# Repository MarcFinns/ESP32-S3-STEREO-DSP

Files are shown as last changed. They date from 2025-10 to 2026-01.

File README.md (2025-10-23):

# ESP32-S3 STEREO DSP BOARD

A board with ESP32-S3, ADC, DAC, LCD display for audio application and beyond. 
While these components can be connected in principle on any breakout board for prototyping, proper power decoupling and series terminator resistors are necessary to limit noise and interference.
This board ensures that all signals are appropriately decoupled and routed, on a single layer PCB.

The board was used to develop the [PiratESP32 FM RDS STEREO ENCODER](https://github.com/MarcFinns/PiratESP32-FM-RDS-STEREO-ENCODER)

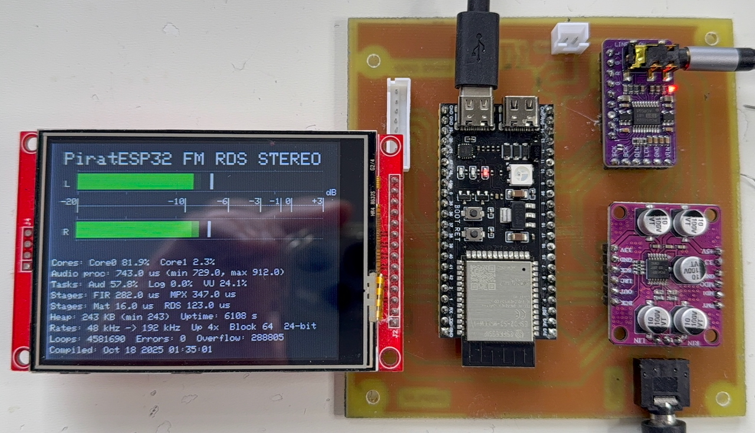
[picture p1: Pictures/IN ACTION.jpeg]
In action


## Features

### ESP32 Board
- **ESP32-S3 N16R8** with dual-core processor with SIMD (vector) instructions to boost DSP applications
- **ADC**: PCM1808 I2S audio ADC (24 bit, up to 96 kHz sample rate, I2S slave)
- **DAC**: PCM5102A I2S audio DAC (16/24/32 bit, up to 192 kHz sample rate, I2S slave)
- **Display (optional)** ILI9341 320×240 TFT LCD (SPI interface)
- **GPIO connector** for LED/buttons or anything else

## Pin Configuration

### I2S Audio
```
Master Clock (shared):  GPIO 8  (tested at 24.576 MHz MCLK)

ADC Input:
  BCK  (Bit Clock):     GPIO 4
  LRCK (Word Select):   GPIO 6
  DIN  (Serial Data):   GPIO 5

DAC Output:
  BCK  (Bit Clock):     GPIO 9
  LRCK (Word Select):   GPIO 11
  DOUT (Serial Data):   GPIO 10

ILI9341 TFT Display
	SCK  (SPI Clock):       GPIO 40
	MOS	I (SPI Data):        GPIO 41
	DC   (Data/Command):    GPIO 42
	CS   (Chip Select):     GPIO 1
	RST  (Reset):           GPIO 2

GPIO Connector
	3V3
	GPIO39
	GPIO38
	GPIO48
	GPIO47
	GPIO21
```

## Important notes

- Some PCM1808 ADC breakout boards have a **very aggressive low pass filter** (the filter is optional from the datasheet, and they chose a wrong capacitor value). This results in a lowpass filter at 6Khz! If sound is muffled, you can just desolder the caps (or break them, it is fine). See picture

- The board is designed to be powered 
both from USB on the ESP and from the Vin, 
without conflicts. However, to enable the board 
to work when powered via USB, it is often 
necessary to connect a jumper on the ESP32-
S3 board that enables 5V out. 
The location of the jumper depends on 
the flavour of the development board! **Look it up!**

- The board can be powered with a power supply connected to the Vin connector (12v max) so that it can work standalone / when not connected to a PC via USB. To that end, a LDO is included in the schematic. It can be skipped if only USB power is necessary. The LDO (AMS1117 family) can be either ADJ or 5V fixed version. A solder jumper on the PCB is provided to select the version. If fixed, connect SJ1 jumper to GND. If adj, connect to R divider. **If left not connected, bad things will happen**

- The PCB and schematic in the folder are correct. The pictures are of my first prototybe that had some mistakes, corrected later!

- SMD components are 0805 size. If uneasy with SMD, one could just redesign the PCB with through hole, keeping the schematic and even the routing - just make it larger

## Breakout boards

The following breakout boards are matching the PCB.
If different ones are used, schematic is still valid but re-routing of the PCB might become necessary.

- [ILI9341 Display](https://nl.aliexpress.com/item/32913890225.html)
- [PCM1808 ADC breakout board](https://nl.aliexpress.com/item/1005006749086540.html)
- [PCM5102A DAC breakout board](https://nl.aliexpress.com/item/1005009648364414.html)
- [ESP32-S3 N16R8](https://nl.aliexpress.com/item/1005007319706057.html)

## References

- [PCM1808 ADC datasheet](https://www.ti.com/lit/ds/symlink/pcm1808.pdf)
- [PCM5102A DAC datasheet](https://www.ti.com/lit/ds/symlink/pcm5102a.pdf)
- [ESP32-S3 documentation](https://www.espressif.com/sites/default/files/documentation/esp32-s3_technical_reference_manual_en.pdf)
- [ESP32 I2S Documentation](https://docs.espressif.com/projects/esp-idf/en/latest/esp32/api-reference/peripherals/i2s.html)

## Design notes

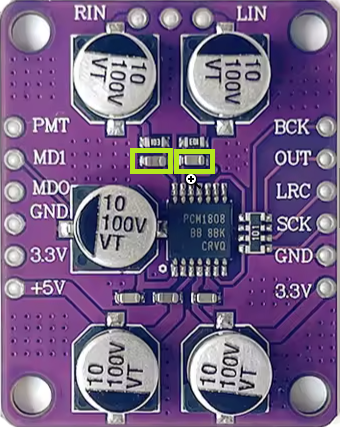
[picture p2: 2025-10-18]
Pictures/PCM1808 Audio ADC CAPS TO REMOVE.png

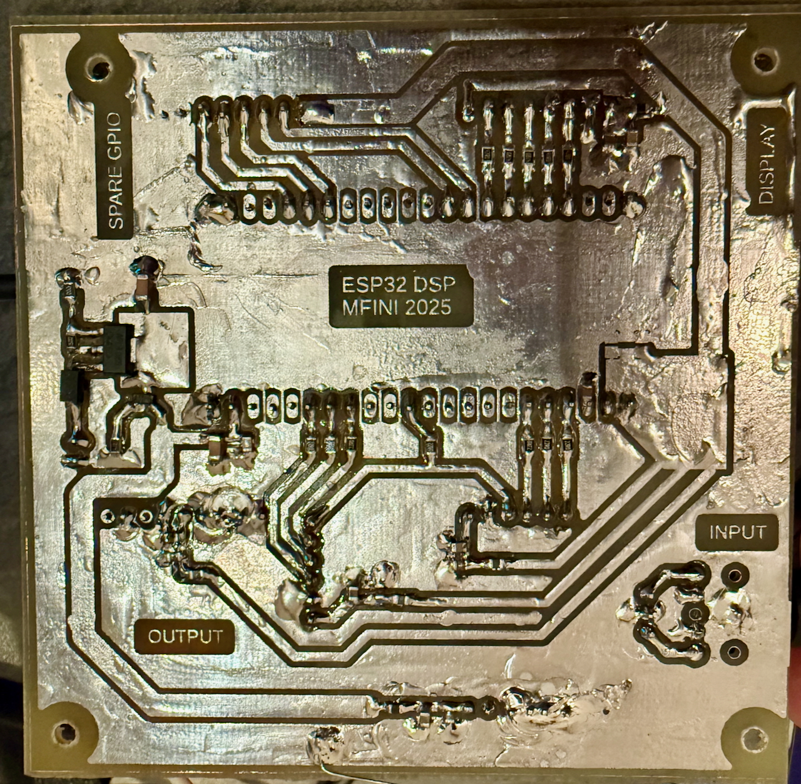
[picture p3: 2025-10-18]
Pictures/PCB BOTTOM.jpeg

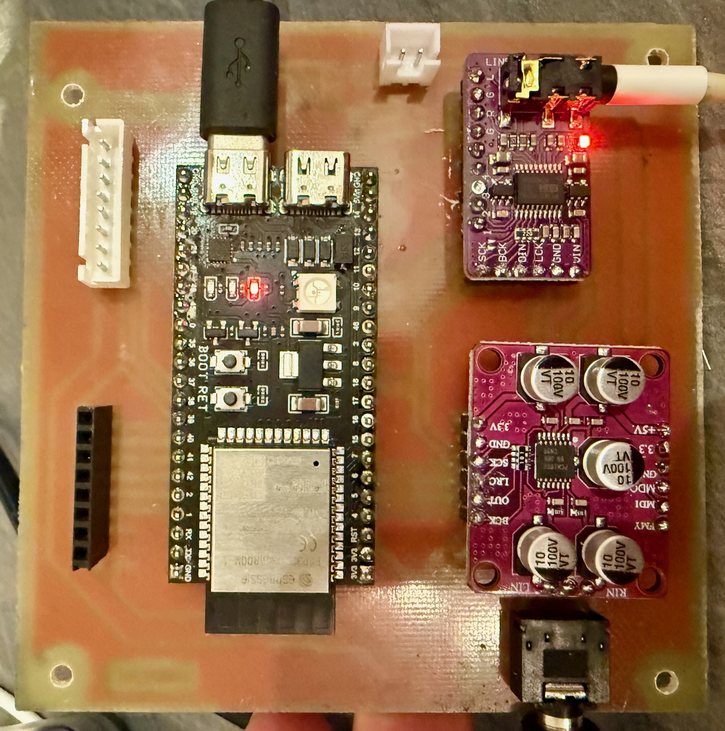
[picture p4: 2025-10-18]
Pictures/PCB TOP.jpeg

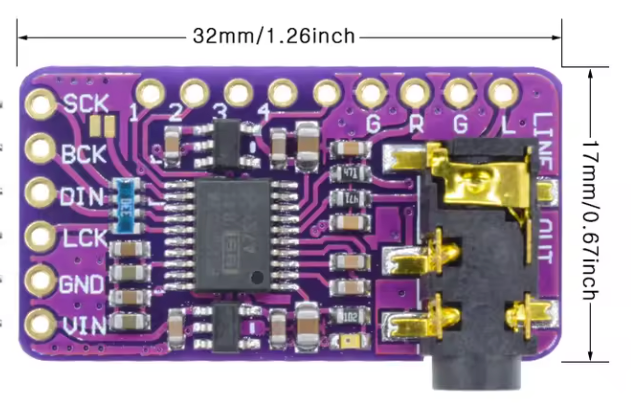
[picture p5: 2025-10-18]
Pictures/DSP5102a Audio DAC.png

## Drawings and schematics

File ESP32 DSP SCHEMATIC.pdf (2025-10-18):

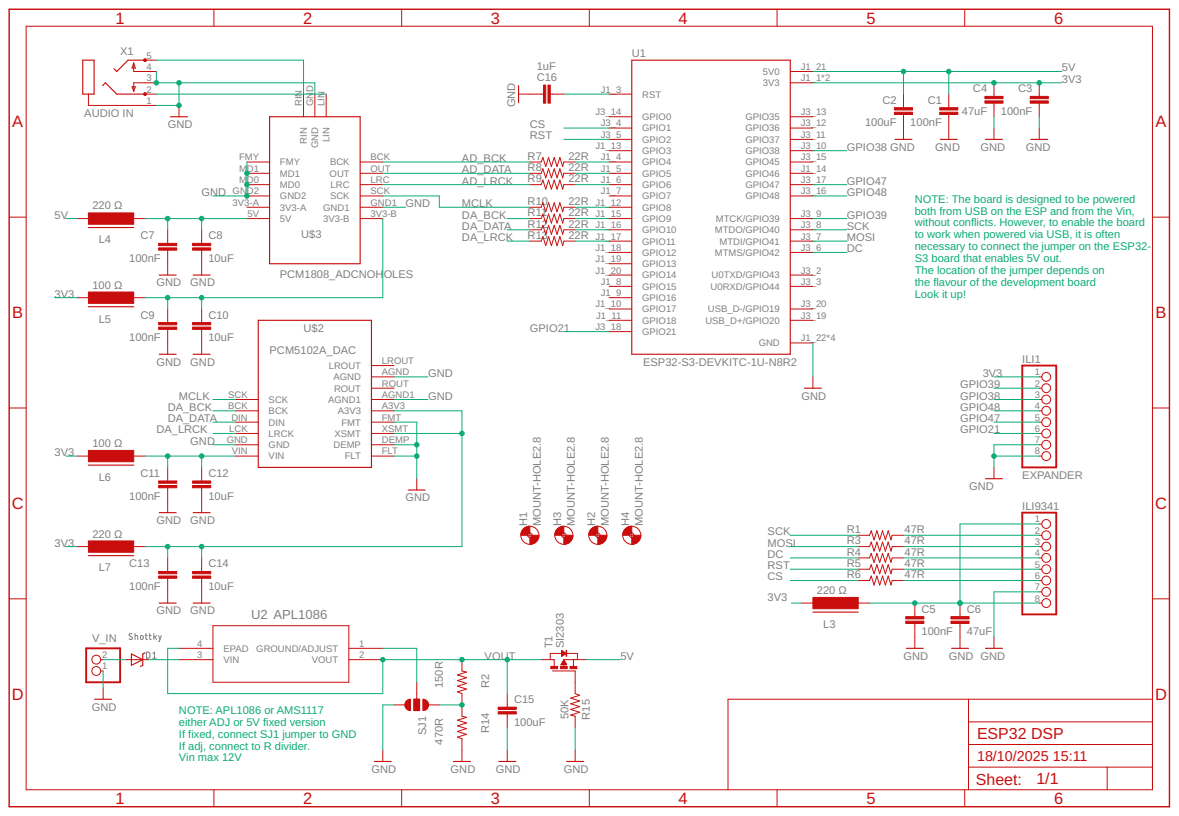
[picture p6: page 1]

NOTE: The board is designed to be powered
both from USB on the ESP and from the Vin, without conflicts. However, to enable the board
to work when powered via USB, it is often
necessary to connect the jumper on the ESP32- S3 board that enables 5V out. The location of the jumper depends on

the flavour of the development board
Look it up!

NOTE: APL1086 or AMS1117
either ADJ or 5V fixed version
If fixed, connect SJ1 jumper to GND
If adj, connect to R divider. Vin max 12V

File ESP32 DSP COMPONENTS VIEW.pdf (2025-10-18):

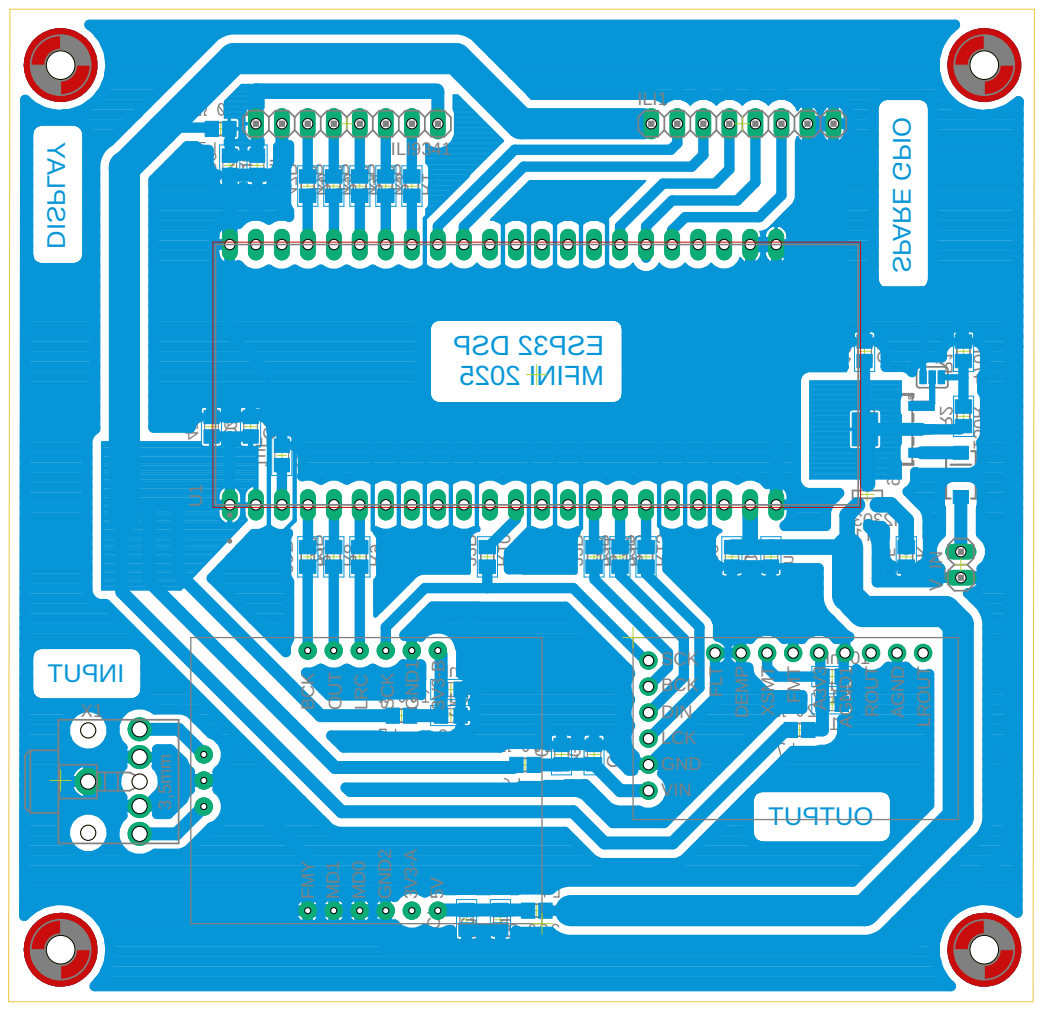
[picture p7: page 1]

ROUT AGND1 A3V3 FMT XSMT DEMP

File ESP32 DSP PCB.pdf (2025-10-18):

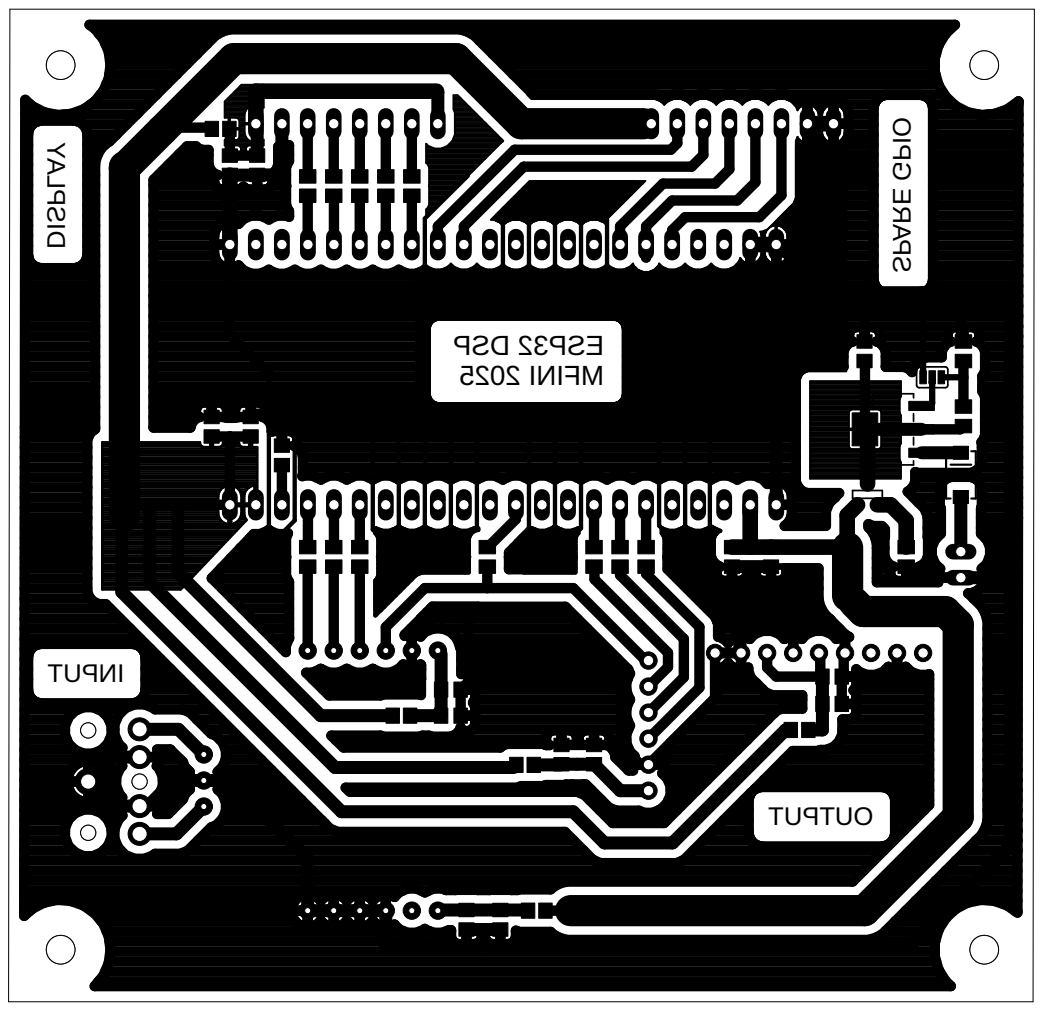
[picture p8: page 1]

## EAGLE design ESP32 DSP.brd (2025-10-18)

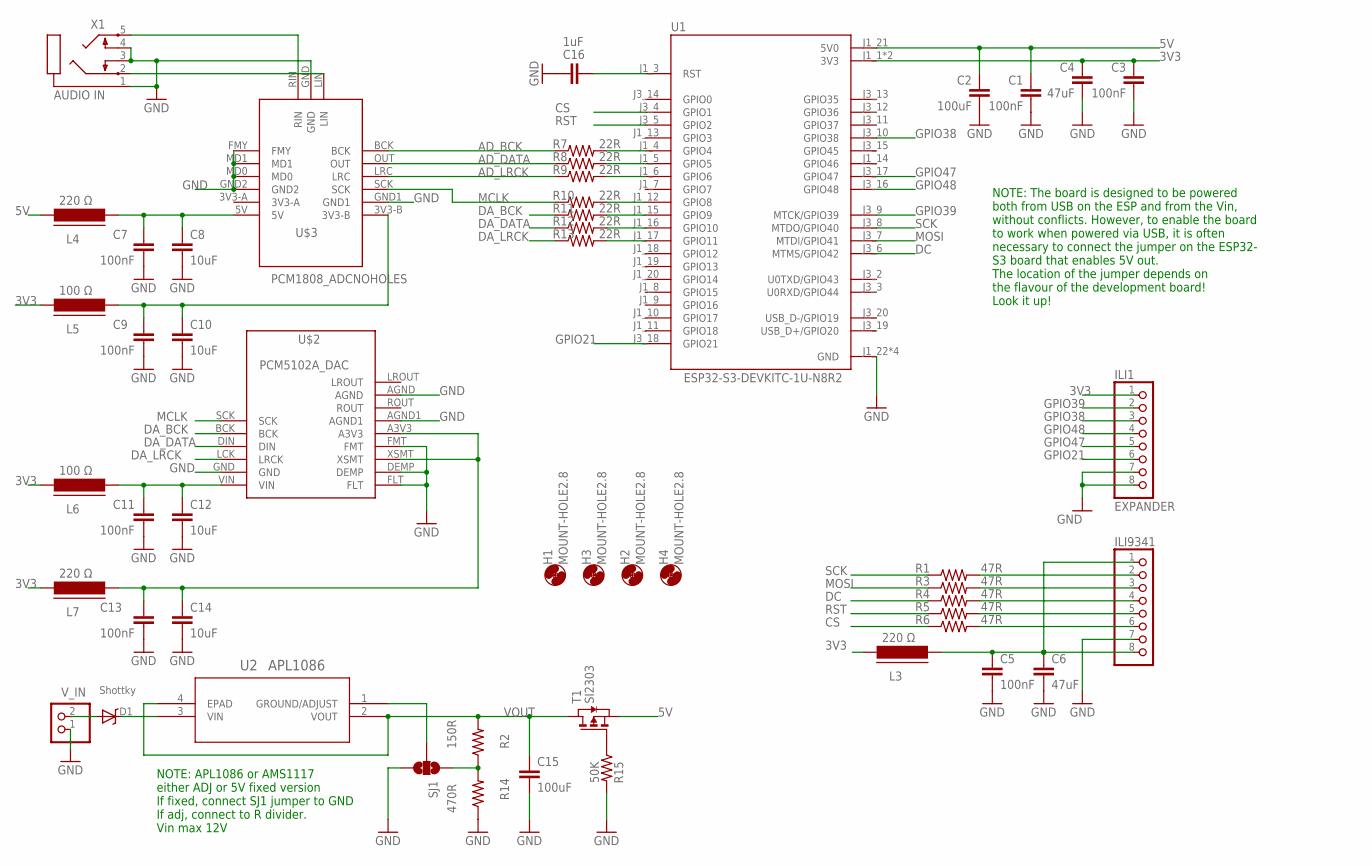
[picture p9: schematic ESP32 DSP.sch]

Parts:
C1, C3, C5, C7, C9, C11, C13: 100nF; C0805
C2, C15: 100uF; C0805
C4, C6: 47uF; C0805
C8, C10, C12, C14: 10uF; C0805
C16: 1uF; C0805
D1: Shottky; SMA-403D
H1, H2, H3, H4: MOUNT-HOLE2.8; 2,8
ILI1: EXPANDER; 1X08
ILI9341: PINHD-1X8; 1X08
L3, L4, L7: 220 Ω; FB805
L5, L6: 100 Ω; FB805
R1, R3, R4, R5, R6: 47R; M0805
R2: 150R; M0805
R7, R8, R9, R10, R11, R12, R13: 22R; M0805
R14: 470R; M0805
R15: 50K; M0805
SJ1: SOLDERJUMPER_2WAYS; SJ_3
T1: SI2303; SOT-23
U1: ESP32-S3-DEVKITC-1U-N8R2; XCVR_ESP32-S3-DEVKITC-1U-N8R2
U2: APL1086; SOT_AMS_ADS
U$2: PCM5102A_DAC; I2S_PCM_5100_SOUNDCARD
U$3: PCM1808_ADCNOHOLES; CMJCU-1808-NOHOLES
V_IN: 5V; 1X02
X1: AUDIO IN; STX3100

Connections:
3V3: C3.1, C4.1, ILI1.1, L3.1, L5.1, L6.1, L7.1, U1.J1_1 (3V3), U1.J1_2 (3V3)
5V: C1.1, C2.1, L4.1, T1.2 (S), U1.J1_21 (5V0)
AD_BCK: R7.1, U$3.BCK
AD_DATA: R8.1, U$3.OUT
AD_LRCK: R9.1, U$3.LRC
CS: R6.1, U1.J3_4 (GPIO1)
DA_BCK: R11.1, U$2.BCK
DA_DATA: R12.1, U$2.DIN
DA_LRCK: R13.1, U$2.LCK (LRCK)
DC: R4.1, U1.J3_6 (MTMS/GPIO42)
GND: C1.2, C2.2, C3.2, C4.2, C5.2, C6.2, C7.2, C8.2, C9.2, C10.2, C11.2, C12.2, C13.2, C14.2, C15.2, C16.2, ILI1.7, ILI1.8, ILI9341.7, R14.1, R15.2, SJ1.3, U1.J1_22 (GND), U1.J3_1 (GND), U1.J3_21 (GND), U1.J3_22 (GND), U$2.AGND, U$2.AGND1, U$2.DEMP, U$2.FLT, U$2.FMT, U$2.GND, U$3.FMY, U$3.GND, U$3.GND1, U$3.GND2, U$3.MD0, U$3.MD1, V_IN.1, X1.1, X1.3, X1.4
GPIO21: ILI1.6, U1.J3_18 (GPIO21)
GPIO38: ILI1.3, U1.J3_10 (GPIO38)
GPIO39: ILI1.2, U1.J3_9 (MTCK/GPIO39)
GPIO47: ILI1.5, U1.J3_17 (GPIO47)
GPIO48: ILI1.4, U1.J3_16 (GPIO48)
MCLK: R10.1, U$2.SCK, U$3.SCK
MOSI: R3.1, U1.J3_7 (MTDI/GPIO41)
unnamed: ILI9341.2, R1.2
unnamed: ILI9341.3, R3.2
unnamed: ILI9341.4, R4.2
unnamed: ILI9341.5, R5.2
unnamed: ILI9341.6, R6.2
unnamed: C11.1, C12.1, L6.2, U$2.VIN
unnamed: C13.1, C14.1, L7.2, U$2.A3V3, U$2.XSMT
unnamed: U$3.RIN, X1.5
unnamed: U$3.LIN, X1.2
unnamed: R2.1, R14.2, SJ1.1
unnamed: D1.C, U2.3 (VIN)
unnamed: C16.1, U1.J1_3 (RST)
unnamed: SJ1.2, U2.1 (GROUND/ADJUST)
unnamed: R15.1, T1.3 (G)
unnamed: R7.2, U1.J1_4 (GPIO4)
unnamed: R8.2, U1.J1_5 (GPIO5)
unnamed: R9.2, U1.J1_6 (GPIO6)
unnamed: R10.2, U1.J1_12 (GPIO8)
unnamed: R11.2, U1.J1_15 (GPIO9)
unnamed: R12.2, U1.J1_16 (GPIO10)
unnamed: R13.2, U1.J1_17 (GPIO11)
unnamed: C9.1, C10.1, L5.2, U$3.3V3-B
unnamed: C7.1, C8.1, L4.2, U$3.5V
unnamed: C5.1, C6.1, ILI9341.1, ILI9341.8, L3.2
RST: R5.1, U1.J3_5 (GPIO2)
SCK: R1.1, U1.J3_8 (MTDO/GPIO40)
VOUT: C15.1, R2.2, T1.1 (D), U2.2 (VOUT), U2.4 (EPAD)
V_IN: D1.A, V_IN.2

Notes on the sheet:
NOTE: APL1086 or AMS1117 either ADJ or 5V fixed version If fixed, connect SJ1 jumper to GND If adj, connect to R divider. Vin max 12V
NOTE: The board is designed to be powered both from USB on the ESP and from the Vin, without conflicts. However, to enable the board to work when powered via USB, it is often necessary to connect the jumper on the ESP32- S3 board that enables 5V out. The location of the jumper depends on the flavou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

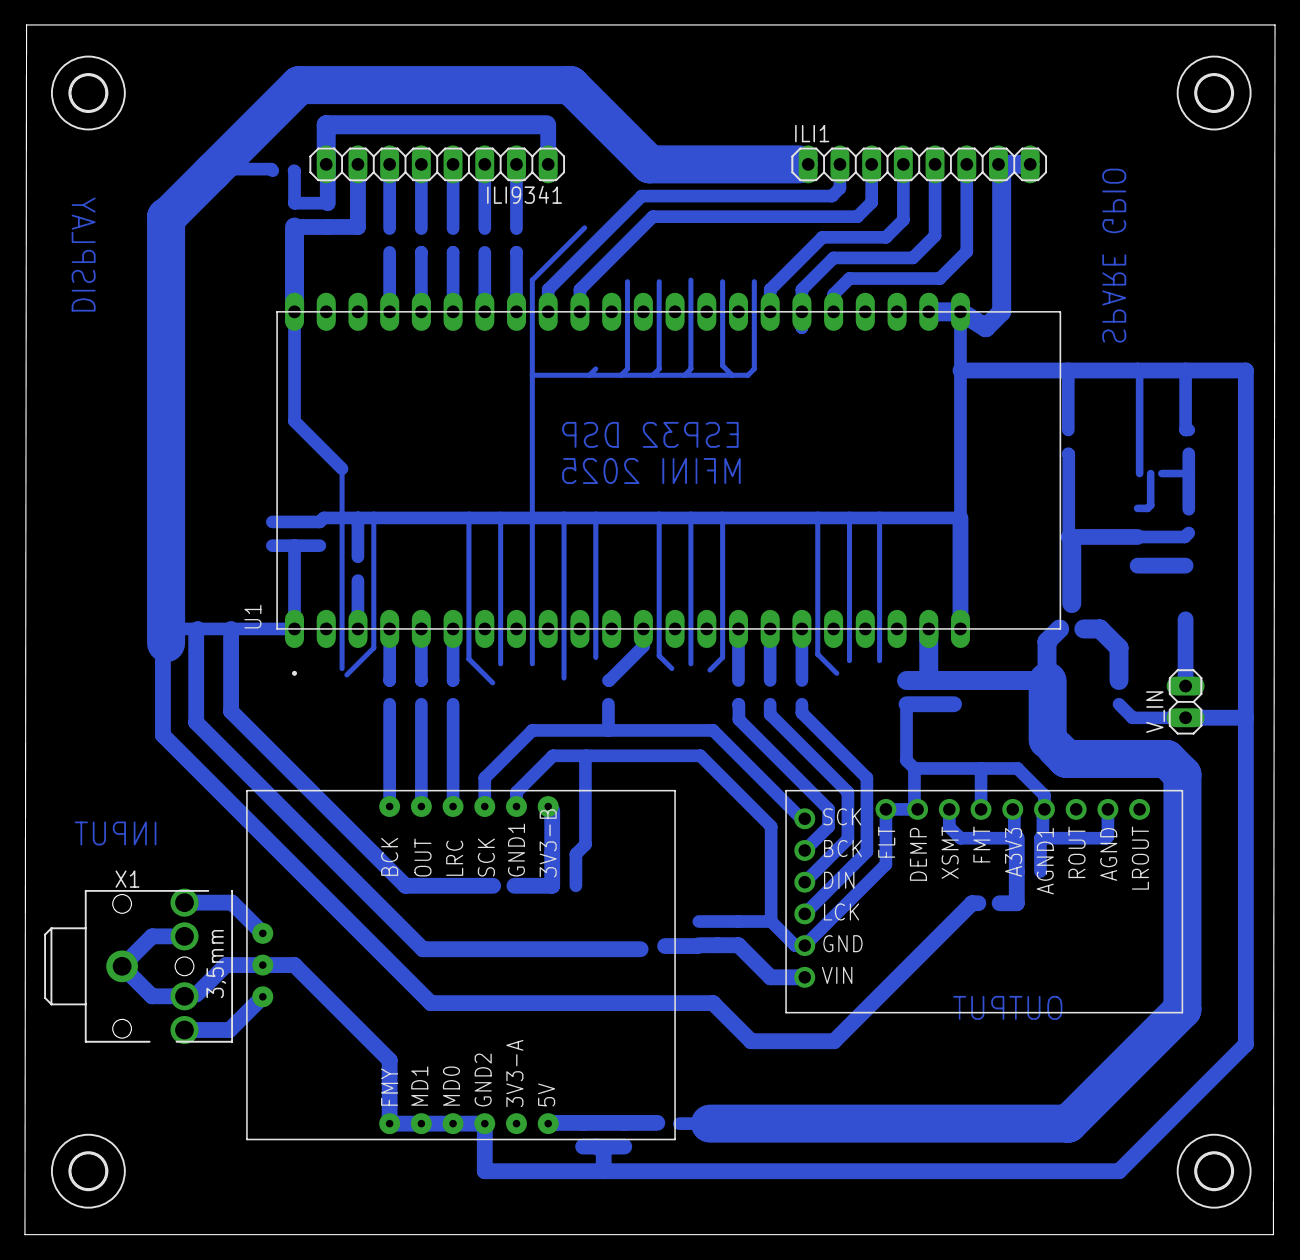
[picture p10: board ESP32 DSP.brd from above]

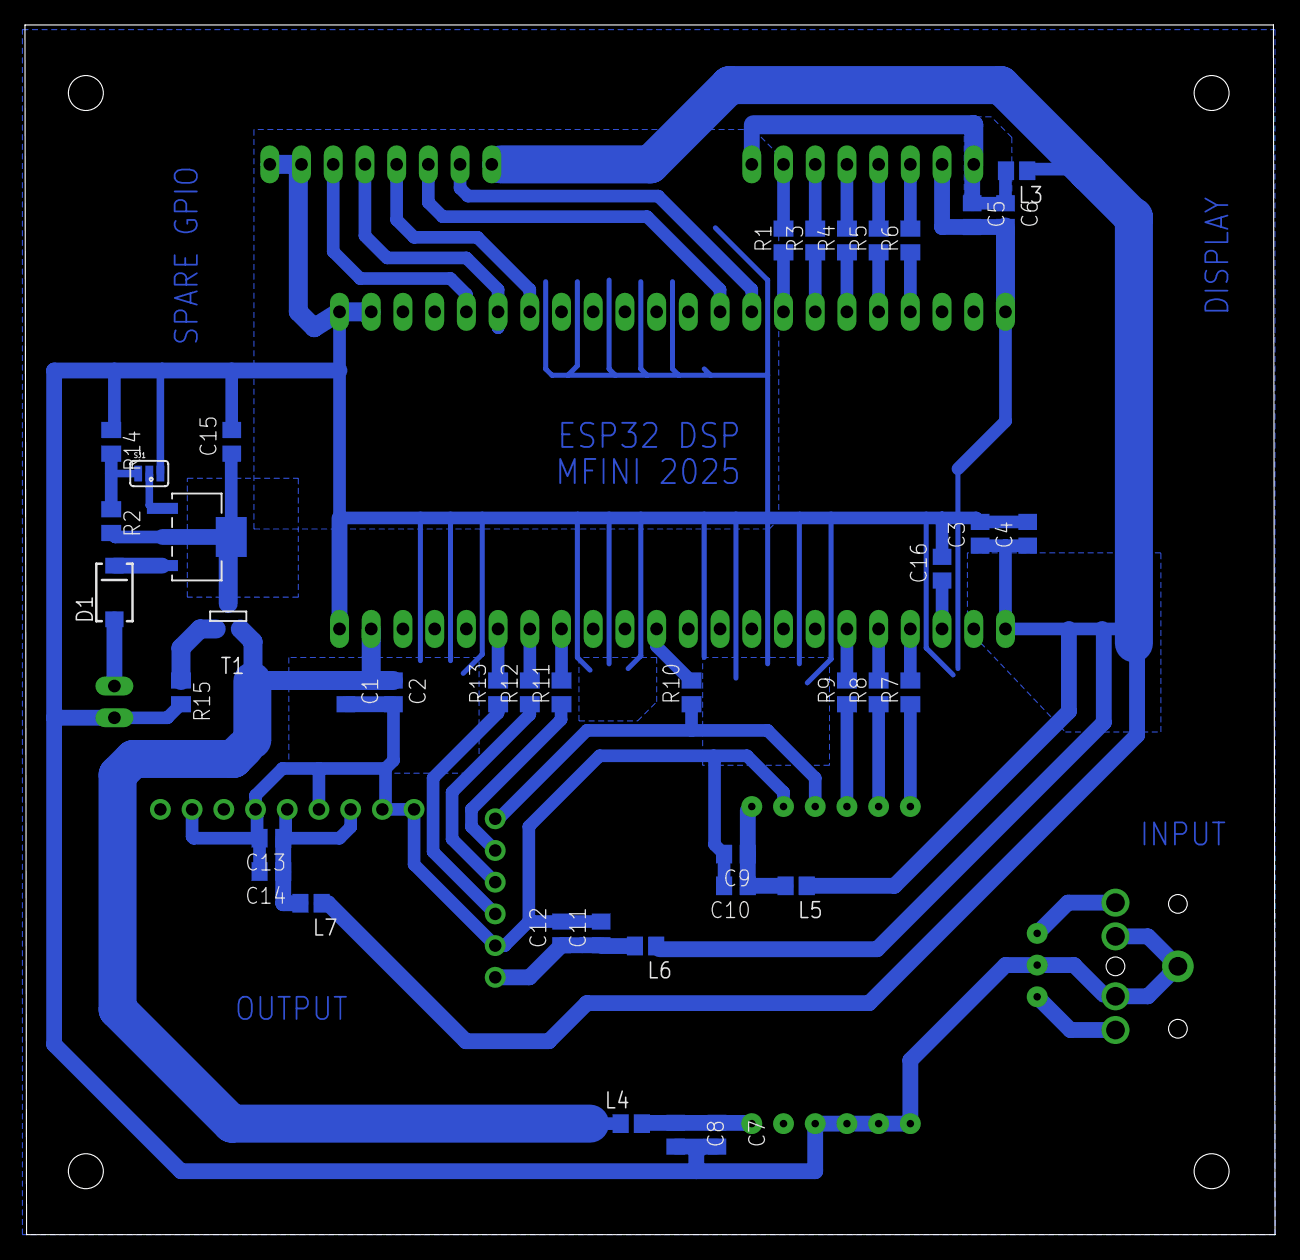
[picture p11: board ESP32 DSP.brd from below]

Board: 2 copper layers, 100.1 x 96.9 mm, 51 parts (40 on the bottom side), 46 nets.

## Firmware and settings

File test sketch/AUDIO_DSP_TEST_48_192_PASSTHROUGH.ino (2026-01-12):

/*
  ESP32-S3 Audio DSP: 48kHz ADC -> 4x Upsample -> 192kHz DAC

  Hardware:
  - PCM1808 ADC (slave mode) @ 48 kHz, 24-bit
  - PCM5102A DAC (slave mode) @ 192 kHz, 24-bit
  - Shared MCLK: 24.576 MHz on GPIO8

  Board: ESP32S3 Dev Module (Arduino-ESP32 3.x)
*/

#include <driver/gpio.h>
#include <driver/i2s_std.h>

// ==== Pin Configuration ====
#define PIN_MCLK 8 // Shared MCLK 24.576 MHz

// DAC (I2S1 - TX) - PCM5102A
#define PIN_DAC_BCK 9
#define PIN_DAC_LRCK 11
#define PIN_DAC_DOUT 10

// ADC (I2S0 - RX) - PCM1808
#define PIN_ADC_BCK 4
#define PIN_ADC_LRCK 6
#define PIN_ADC_DIN 5

// ==== Audio Configuration ====
#define SAMPLE_RATE_ADC 48000
#define SAMPLE_RATE_DAC 192000
#define UPSAMPLE_FACTOR 4
#define BLOCK_SIZE 64 // Frames per block (reduced for lower latency)
#define BITS_PER_SAMPLE 24
#define BYTES_PER_SAMPLE 4 // 24-bit in 32-bit container

// I2S channel handles
i2s_chan_handle_t tx_handle = NULL;
i2s_chan_handle_t rx_handle = NULL;

// Audio buffers
int32_t rx_buffer[BLOCK_SIZE * 2];                   // Stereo input @ 48kHz
int32_t tx_buffer[BLOCK_SIZE * UPSAMPLE_FACTOR * 2]; // Stereo output @ 192kHz

// ==== Improved Upsampler: Cubic Hermite Interpolation ====
// Much better than linear, avoids aliasing artifacts, simple & fast

// Cubic Hermite basis functions for smooth interpolation
static inline float hermite_h00(float t) { return 2*t*t*t - 3*t*t + 1; }
static inline float hermite_h10(float t) { return t*t*t - 2*t*t + t; }
static inline float hermite_h01(float t) { return -2*t*t*t + 3*t*t; }
static inline float hermite_h11(float t) { return t*t*t - t*t; }

// History buffer for samples before current block
static int32_t prev_L = 0, prev_R = 0;

void upsample_4x_polyphase(const int32_t *input, int32_t *output,
                           size_t num_frames)
{
  // 4x cubic Hermite interpolation
  // Uses smooth interpolation curves instead of linear, much better quality
  for (size_t i = 0; i < num_frames; i++)
  {
    // Get surrounding samples (with history)
    int32_t L0 = (i == 0) ? prev_L : input[(i - 1) * 2];
    int32_t R0 = (i == 0) ? prev_R : input[(i - 1) * 2 + 1];
    int32_t L1 = input[i * 2];
    int32_t R1 = input[i * 2 + 1];
    int32_t L2 = (i == num_frames - 1) ? L1 : input[(i + 1) * 2];
    int32_t R2 = (i == num_frames - 1) ? R1 : input[(i + 1) * 2 + 1];
    int32_t L3 = (i >= num_frames - 2) ? L2 : input[(i + 2) * 2];
    int32_t R3 = (i >= num_frames - 2) ? R2 : input[(i + 2) * 2 + 1];

    // Compute derivatives for Hermite spline (simple 3-point approximation)
    float m1_L = (float)(L2 - L0) * 0.5f;
    float m2_L = (float)(L3 - L1) * 0.5f;
    float m1_R = (float)(R2 - R0) * 0.5f;
    float m2_R = (float)(R3 - R1) * 0.5f;

    // Generate 4 output samples per input sample
    for (int frac = 0; frac < 4; frac++)
    {
      float t = frac * 0.25f;  // Fractional position 0, 0.25, 0.5, 0.75

      // Hermite basis evaluation
      float h00 = hermite_h00(t);
      float h10 = hermite_h10(t);
      float h01 = hermite_h01(t);
      float h11 = hermite_h11(t);

      // Interpolate left and right channels
      float out_L_norm = h00 * (float)L1 / 2147483648.0f +
                         h10 * m1_L / 2147483648.0f +
                         h01 * (float)L2 / 2147483648.0f +
                         h11 * m2_L / 2147483648.0f;

      float out_R_norm = h00 * (float)R1 / 2147483648.0f +
                         h10 * m1_R / 2147483648.0f +
                         h01 * (float)R2 / 2147483648.0f +
                         h11 * m2_R / 2147483648.0f;

      // Convert back to MSB-aligned 32-bit
      int32_t out_L = (int32_t)(out_L_norm * 2147483648.0f);
      int32_t out_R = (int32_t)(out_R_norm * 2147483648.0f);

      // Clamp to prevent overflow
      if (out_L > 2147483647) out_L = 2147483647;
      if (out_L < -2147483648) out_L = -2147483648;
      if (out_R > 2147483647) out_R = 2147483647;
      if (out_R < -2147483648) out_R = -2147483648;

      size_t out_idx = i * 8 + frac * 2;
      output[out_idx] = out_L;
      output[out_idx + 1] = out_R;
    }
  }

  // Save last sample for next block
  if (num_frames > 0)
  {
    prev_L = input[(num_frames - 1) * 2];
    prev_R = input[(num_frames - 1) * 2 + 1];
  }
}

// ==== I2S Setup Functions ====

bool setup_i2s_tx()
{
  Serial.println("Initializing I2S TX (DAC @ 192kHz)...");

  // Channel configuration
  i2s_chan_config_t chan_cfg =
      I2S_CHANNEL_DEFAULT_CONFIG(I2S_NUM_1, I2S_ROLE_MASTER);
  chan_cfg.auto_clear = true;
  chan_cfg.dma_desc_num = 6;
  chan_cfg.dma_frame_num = 240;

  esp_err_t ret = i2s_new_channel(&chan_cfg, &tx_handle, NULL);
  if (ret != ESP_OK)
  {
    Serial.printf("Failed to create TX channel: %d\n", ret);
    return false;
  }

  // Slot configuration for PCM5102A
  i2s_std_slot_config_t slot_cfg = I2S_STD_PHILIPS_SLOT_DEFAULT_CONFIG(
      I2S_DATA_BIT_WIDTH_32BIT, I2S_SLOT_MODE_STEREO);
  slot_cfg.slot_bit_width = I2S_SLOT_BIT_WIDTH_32BIT;
  slot_cfg.ws_width = 32;
  slot_cfg.ws_pol = false;
  slot_cfg.bit_shift = true;
  slot_cfg.left_align = true; // PCM5102A expects MSB-aligned data
  slot_cfg.big_endian = false;
  slot_cfg.bit_order_lsb = false;

  // Clock configuration
  i2s_std_clk_config_t clk_cfg = {};
  clk_cfg.sample_rate_hz = SAMPLE_RATE_DAC;
  clk_cfg.clk_src = I2S_CLK_SRC_PLL_160M;
  clk_cfg.mclk_multiple = I2S_MCLK_MULTIPLE_128;

  // GPIO configuration
  i2s_std_gpio_config_t gpio_cfg = {};
  gpio_cfg.mclk = (gpio_num_t)PIN_MCLK;
  gpio_cfg.bclk = (gpio_num_t)PIN_DAC_BCK;
  gpio_cfg.ws = (gpio_num_t)PIN_DAC_LRCK;
  gpio_cfg.dout = (gpio_num_t)PIN_DAC_DOUT;
  gpio_cfg.din = I2S_GPIO_UNUSED;
  gpio_cfg.invert_flags.mclk_inv = false;
  gpio_cfg.invert_flags.bclk_inv = false;
  gpio_cfg.invert_flags.ws_inv = false;

  // Standard mode configuration
  i2s_std_config_t std_cfg = {};
  std_cfg.clk_cfg = clk_cfg;
  std_cfg.slot_cfg = slot_cfg;
  std_cfg.gpio_cfg = gpio_cfg;

  ret = i2s_channel_init_std_mode(tx_handle, &std_cfg);
  if (ret != ESP_OK)
  {
    Serial.printf("Failed to init TX std mode: %d\n", ret);
    return false;
  }

  ret = i2s_channel_enable(tx_handle);
  if (ret != ESP_OK)
  {
    Serial.printf("Failed to enable TX channel: %d\n", ret);
    return false;
  }

  Serial.println("I2S TX initialized successfully");
  Serial.printf("  Sample Rate: %d Hz\n", SAMPLE_RATE_DAC);
  Serial.printf("  MCLK: %.3f MHz (GPIO%d)\n",
                (SAMPLE_RATE_DAC * 128) / 1000000.0, PIN_MCLK);
  Serial.printf("  BCK: %.3f MHz (GPIO%d)\n",
                (SAMPLE_RATE_DAC * 64) / 1000000.0, PIN_DAC_BCK);
  Serial.printf("  LRCK: %d Hz (GPIO%d)\n", SAMPLE_RATE_DAC, PIN_DAC_LRCK);

  return true;
}

bool setup_i2s_rx()
{
  Serial.println("Initializing I2S RX (ADC @ 48kHz)...");

  // Channel configuration
  i2s_chan_config_t chan_cfg =
      I2S_CHANNEL_DEFAULT_CONFIG(I2S_NUM_0, I2S_ROLE_MASTER);
  chan_cfg.auto_clear = true;
  chan_cfg.dma_desc_num = 6;
  chan_cfg.dma_frame_num = 240;

  esp_err_t ret = i2s_new_channel(&chan_cfg, NULL, &rx_handle);
  if (ret != ESP_OK)
  {
    Serial.printf("Failed to create RX channel: %d\n", ret);
    return false;
  }

  // Slot configuration for PCM1808
  i2s_std_slot_config_t slot_cfg = I2S_STD_PHILIPS_SLOT_DEFAULT_CONFIG(
      I2S_DATA_BIT_WIDTH_32BIT, I2S_SLOT_MODE_STEREO);
  slot_cfg.slot_bit_width = I2S_SLOT_BIT_WIDTH_32BIT;
  slot_cfg.ws_width = 32;
  slot_cfg.ws_pol = false;
  slot_cfg.bit_shift = true;
  slot_cfg.left_align = true; // PCM1808 outputs MSB-aligned data
  slot_cfg.big_endian = false;
  slot_cfg.bit_order_lsb = false;

  // Clock configuration
  i2s_std_clk_config_t clk_cfg = {};
  clk_cfg.sample_rate_hz = SAMPLE_RATE_ADC;
  clk_cfg.clk_src = I2S_CLK_SRC_PLL_160M;
  clk_cfg.mclk_multiple = I2S_MCLK_MULTIPLE_512;

  // GPIO configuration
  i2s_std_gpio_config_t gpio_cfg = {};
  gpio_cfg.mclk = I2S_GPIO_UNUSED; // TX already drives MCLK
  gpio_cfg.bclk = (gpio_num_t)PIN_ADC_BCK;
  gpio_cfg.ws = (gpio_num_t)PIN_ADC_LRCK;
  gpio_cfg.dout = I2S_GPIO_UNUSED;
  gpio_cfg.din = (gpio_num_t)PIN_ADC_DIN;
  gpio_cfg.invert_flags.mclk_inv = false;
  gpio_cfg.invert_flags.bclk_inv = false;
  gpio_cfg.invert_flags.ws_inv = false;

  // Standard mode configuration
  i2s_std_config_t std_cfg = {};
  std_cfg.clk_cfg = clk_cfg;
  std_cfg.slot_cfg = slot_cfg;
  std_cfg.gpio_cfg = gpio_cfg;

  ret = i2s_channel_init_std_mode(rx_handle, &std_cfg);
  if (ret != ESP_OK)
  {
    Serial.printf("Failed to init RX std mode: %d\n", ret);
    return false;
  }

  ret = i2s_channel_enable(rx_handle);
  if (ret != ESP_OK)
  {
    Serial.printf("Failed to enable RX channel: %d\n", ret);
    return false;
  }

  Serial.println("I2S RX initialized successfully");
  Serial.printf("  Sample Rate: %d Hz\n", SAMPLE_RATE_ADC);
  Serial.printf("  MCLK: %.3f MHz (from TX GPIO%d)\n",
                (SAMPLE_RATE_ADC * 512) / 1000000.0, PIN_MCLK);
  Serial.printf("  BCK: %.3f MHz (GPIO%d)\n",
                (SAMPLE_RATE_ADC * 64) / 1000000.0, PIN_ADC_BCK);
  Serial.printf("  LRCK: %d Hz (GPIO%d)\n", SAMPLE_RATE_ADC, PIN_ADC_LRCK);

  return true;
}

// ==== Arduino Setup ====

void setup()
{
  Serial.begin(115200);
  delay(1000);

  Serial.println("\n\n========================================");
  Serial.println("ESP32-S3 Audio DSP: 48kHz -> 192kHz");
  Serial.println("========================================\n");

  // Initialize TX first (it generates MCLK)
  if (!setup_i2s_tx())
  {
    Serial.println("\nERROR: TX initialization failed!");
    while (1)
      delay(1000);
  }

  delay(100); // Let TX MCLK stabilize

  // Initialize RX (uses MCLK from TX)
  if (!setup_i2s_rx())
  {
    Serial.println("\nERROR: RX initialization failed!");
    while (1)
      delay(1000);
  }

  Serial.println("\n========================================");
  Serial.println("System Ready - Starting Audio Processing");
  Serial.println("========================================\n");

  delay(500);
}

// ==== Arduino Loop ====

void loop()
{
  size_t bytes_read = 0;

  // Read audio from ADC
  esp_err_t ret = i2s_channel_read(rx_handle, rx_buffer, sizeof(rx_buffer),
                                   &bytes_read, portMAX_DELAY);

  if (ret != ESP_OK)
  {
    Serial.printf("Read error: %d\n", ret);
    return;
  }

  if (bytes_read == 0)
  {
    return;
  }

  // Calculate number of frames received
  size_t frames_read =
      bytes_read / (2 * BYTES_PER_SAMPLE); // Stereo = 2 channels

  // Upsample 4x using polyphase FIR filter
  upsample_4x_polyphase(rx_buffer, tx_buffer, frames_read);

  // Write to DAC
  size_t bytes_to_write = frames_read * UPSAMPLE_FACTOR * 2 * BYTES_PER_SAMPLE;
  size_t bytes_written = 0;

  ret = i2s_channel_write(tx_handle, tx_buffer, bytes_to_write, &bytes_written,
                          portMAX_DELAY);

  if (ret != ESP_OK)
  {
    Serial.printf("Write error: %d\n", ret);
  }

  // Optional: Monitor for underruns
  if (bytes_written != bytes_to_write)
  {
    Serial.printf("Warning: Underrun (wrote %d/%d bytes)\n", bytes_written,
                  bytes_to_write);
  }
}

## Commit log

2025-10-18 Initial commit: ESP32-S3 Stereo DSP project files
    [ESP32 DSP.brd, ESP32 DSP.sch]
2025-10-18 Fix heading format for Boards section in README
    Corrected heading formatting for 'Boards' section.
2025-10-18 Rename 'Boards' section to 'Breakout boards'
    Updated section title from 'Boards' to 'Breakout boards' in README.
2025-10-22 Update README with project reference
    Added a reference to the PiratESP32 FM RDS Stereo Encoder project.
2025-10-22 Add image of PCB to README
    Added an image to the README to show the PCB in action.
2025-10-22 Fix formatting of ADC feature in README.md
2026-01-12 Create AUDIO_DSP_TEST_48_192_PASSTHROUGH.ino
    A simple sketch to test the board.
2026-01-12 Add ESP32-S3 Audio DSP sketch for upsampling
    Added an ESP32-S3 Audio DSP sketch for 48kHz to 192kHz audio processing with I2S configuration and cubic Hermite interpolation for upsampling.

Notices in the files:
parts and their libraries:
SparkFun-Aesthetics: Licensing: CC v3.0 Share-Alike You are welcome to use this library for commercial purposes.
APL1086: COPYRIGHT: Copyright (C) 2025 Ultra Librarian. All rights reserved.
